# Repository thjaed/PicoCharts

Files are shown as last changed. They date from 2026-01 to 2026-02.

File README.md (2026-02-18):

# PicoCharts
 PicoCharts is a pocket-sized embedded device that lets students view their timetable, homework, behaviour, and attendance without needing a phone. I built this device using a Raspberry Pi Pico 2 W and I am using an online API for the data (ClassCharts). Hence the name "PicoCharts".

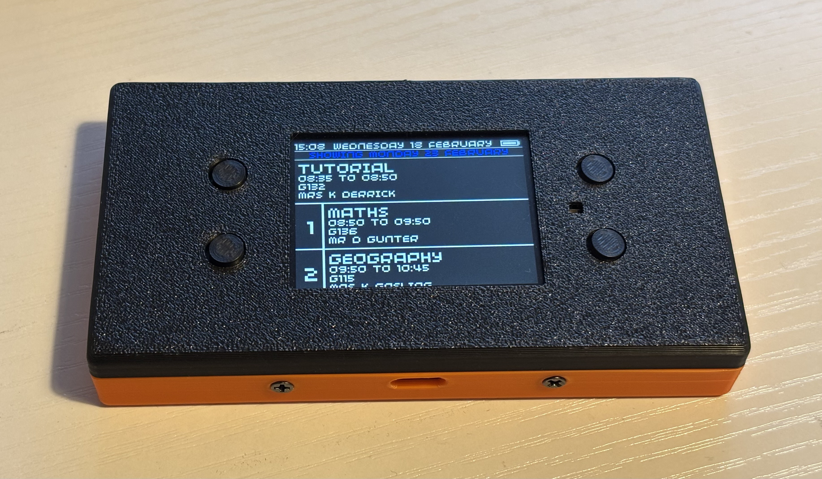
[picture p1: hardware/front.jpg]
Front
 

## Backstory
 After my school banned the use of mobile phones, I had the idea of creating a device that could let me view my timetable at school. This was also a good opportunity to improve my hardware design & soldering skills, and to improve my programming.
 
 The project started by just reading an exported calendar file from Outlook (project [cal-pal](https://github.com/thjaed/cal-pal)), but quickly grew after I upgraded to the Pico 2 W with wireless connectivity. I found documentation for the API of the platform my school uses, thank you to the creators of https://classchartsapi.github.io/api-docs/, without this community resource my project would not have been possible. I developed a Python & MicroPython wrapper for the API (https://github.com/thjaed/classcharts-api-python) which is accessible for anyone else wanting to integrate with the ClassCharts API.

## Features
 Here are some features of PicoCharts:

 ### Timetable
  - Label next to lessons with homework due
  - Timetables for different days can be viewed
  - Custom breaks can be added, e.g. Lunch or Break
  - 'Next' label on lessons
  - Lessons in the past are automatically removed
  - Auto-updates after a new day
  - View timetables for different days and store them offline

 ### Homework
  - Front LED turns on if there is unseen homework
  - Description can be viewed by clicking on a homework task
  - Due-date colour coded to make it clear if a homework is late or not
  - Homework marked as seen on ClassCharts when it is clicked on

 ### Attendance
  - Colour-coded background based on percentage
  - Easily choose a time range (Since August, This Week or Last Week)

 ### Behaviour
  - Easily choose a time range (Since August, This Week or Last Week)

## Using PicoCharts yourself
 To use PicoCharts, all you need is a Raspberry Pi Pico 2 W and a Pimoroni Pico Display Pack 2.0" (No soldering required, just attach a headered Pico 2 W to the back of the Pico Display). The Pico LiPo SHIM is only required if you want to use PicoCharts with a battery and the Adafruit LC709203F is only required if you want the battery percentage in the corner of the screen. Note that you will need to solder these battery boards.

 In terms of software, you need to install [Pimoroni's MicroPython build](https://github.com/pimoroni/pimoroni-pico-rp2350/releases/latest) to your Pico. Then copy everything in the [src](/src/) folder to your Pico. You can do this in the IDE 'Thonny'.
 
 Make sure to modify [secrets.py](/src/secrets.py), this is where you put your ClassCharts login details and WiFi networks.
 
 In [config.py](/src/config.py), you can change settings such as timezone and brightness. This is also where you define what times your breaks are, so make sure to change the times to reflect your school day. Disable ENABLE_BATTERY_gauge (enabled by default) if you are not using the battery gauge.

 If you decide to replicate my hardware, there are [STL Files](/hardware/stl_files/) for my design.

## Hardware
 ### I used the following hardware:
  - Pimoroni Pico Display Pack 2.0" - this is the screen and has the built in buttons and RGB LED
  - Raspberry Pi Pico 2W
  - Adafruit LC709203F battery fuel gauge - measure the charge level of the battery
  - Pimoroni Pico LiPo SHIM
  - USB-C breakout board with 512K resistors (so it works with modern chargers)
  - 1200mAh LiPo battery

At the start, I was using the Pico Display with the Pico plugged in to the headers on the back. But this made the device too thick so I decided to remove the headers from the display and solder 30 AWG wire directly. In the process of removing the headers I accidentally ripped off some pads (I had bad equipment) including the 3V supply. But luckily I traced it back to a resistor and soldered on to it, which saved the screen.

I used a USB-C breakout board to add USB-C. I soldered to the touch pads underneath the Pi to get USB data signals working over it, so I can program the Pi through the USB-C port as well.

 ### Wiring diagram
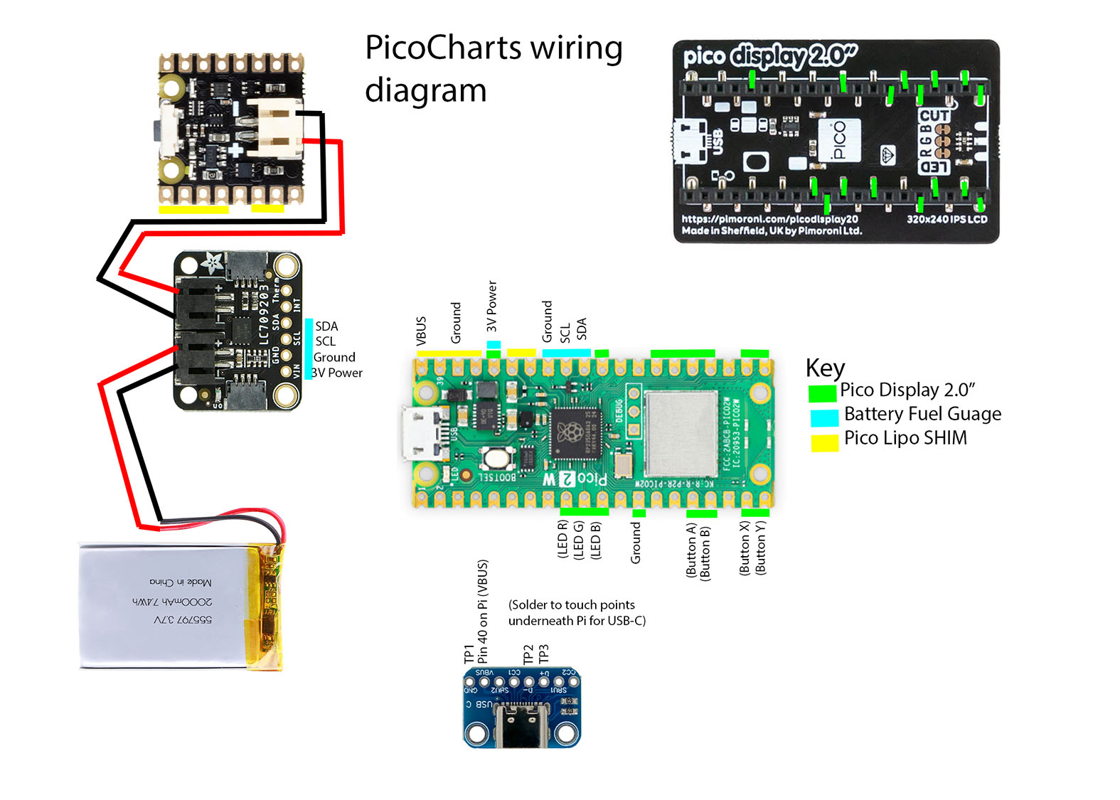
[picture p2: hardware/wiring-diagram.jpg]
Wiring Diagram
  

 ### Internals
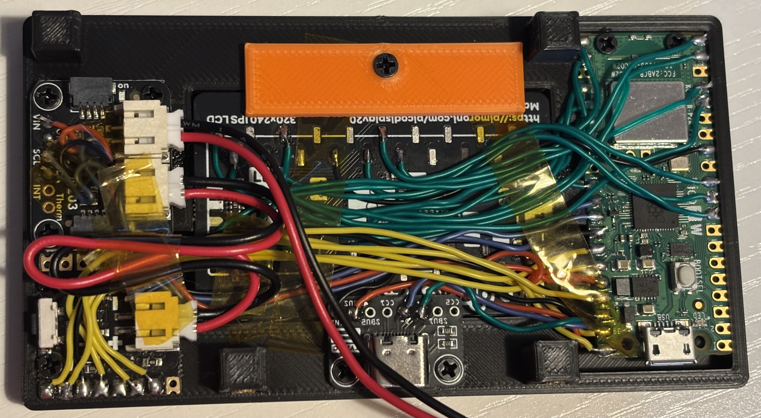
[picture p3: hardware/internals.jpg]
Internals
  
  
 ### Back
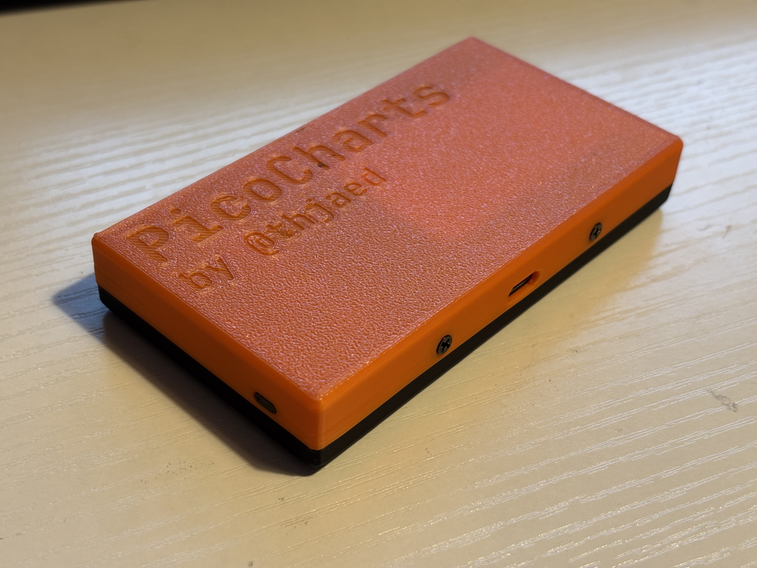
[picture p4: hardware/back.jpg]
Back
  

## Software
 ### High-level overview
  PicoCharts gets and displays data by first requesting data from the ClassCharts API. This happens at bootup and at a set interval, when the device is sleeping. This data is then simplified and saved into a JSON file in the flash storage. When a page is opened on the device, the corresponding file is read and loaded into a list. This list is then read by a draw function, which then puts the data on the screen inside scrollable pages and organised boxes.

  If the user requests to view the timetable for a different day and the JSON file for that day is not saved, then the data is requested and saved into a new JSON file. If the file already exists, it is opened with little to no waiting.
 
 ### Use of AI generated code
  AI was used selectively for complex date arithmetic and initial scrolling logic. All AI-assisted code is clearly commented.

## Acknowledgements
 In this project I used:

 - pybuttons by @oscaracena - https://github.com/oscaracena/pybuttons
 - ClassCharts API Docs  by @veloii - https://github.com/classchartsapi/api-docs
 - PicoGraphics by @pimoroni - https://github.com/pimoroni/pimoroni-pico/tree/main/micropython/modules/picographics
 - MicroPython_LC709203F by @chris-reichl - https://github.com/chris-reichl/MicroPython_LC709203F
 - I based my 3D printed case on: Pimoroni Pico Display pack 2.0 Case by @PMcGregor_848641 - https://www.printables.com/model/473270-pimoroni-pico-display-pack-20-case

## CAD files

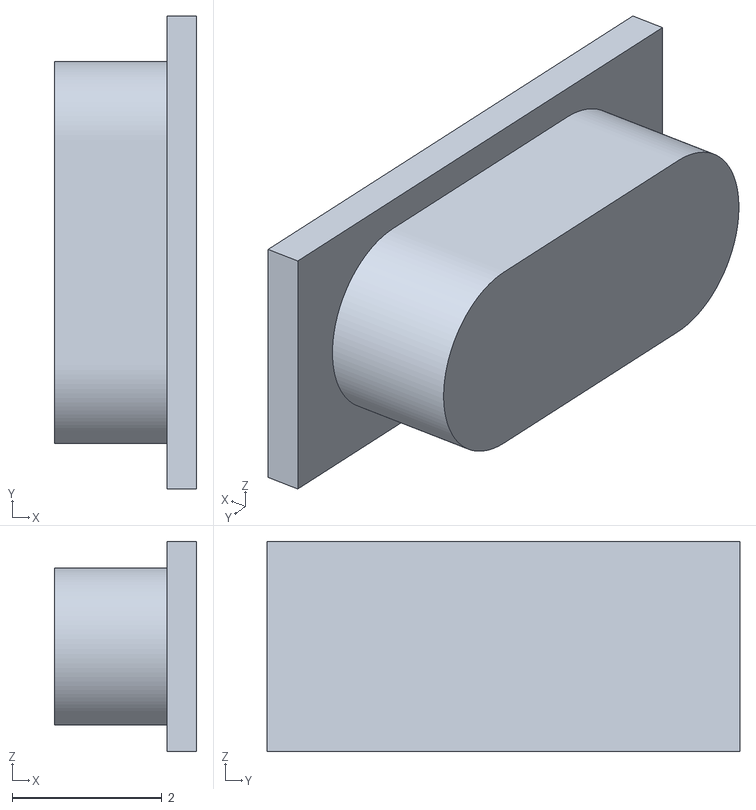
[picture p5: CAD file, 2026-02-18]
hardware/stl_files/pwr_btn.stl
1.90 x 6.30 x 2.80

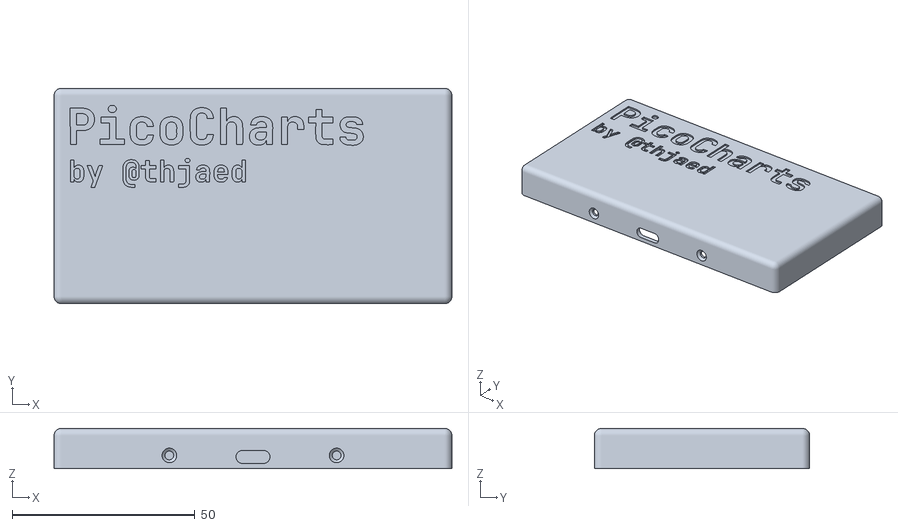
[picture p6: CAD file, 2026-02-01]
hardware/stl_files/back_cover.stl
109.0 x 59.0 x 11.0

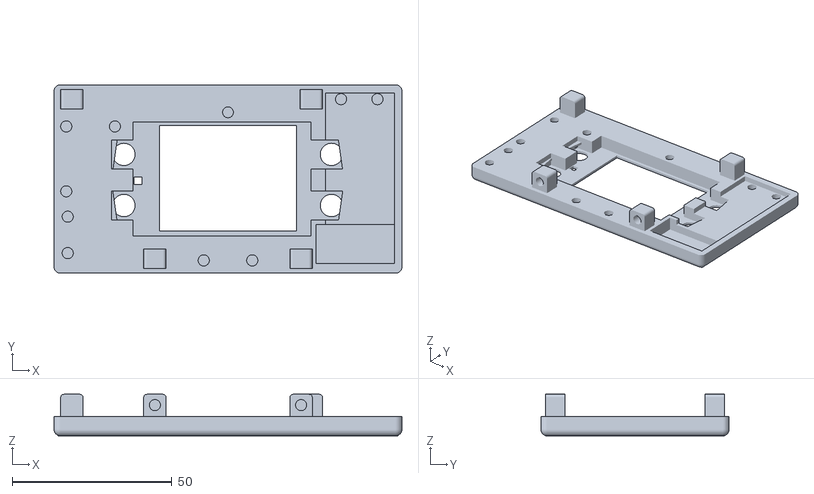
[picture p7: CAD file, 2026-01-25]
hardware/stl_files/base.stl
109.0 x 59.0 x 13.0

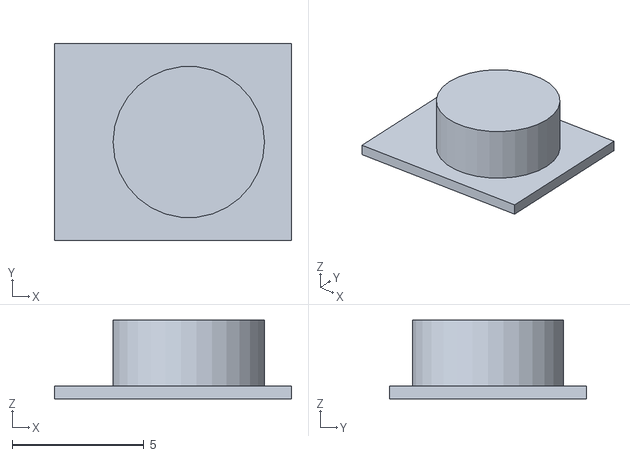
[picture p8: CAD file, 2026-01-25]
hardware/stl_files/X_Y_buttons.stl
9.00 x 7.50 x 3.00

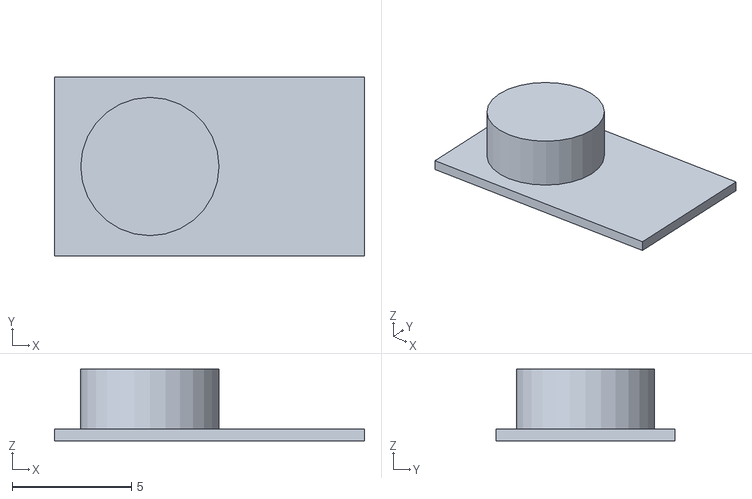
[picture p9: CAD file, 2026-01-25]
hardware/stl_files/A_B_buttons.stl
13.0 x 7.50 x 3.00

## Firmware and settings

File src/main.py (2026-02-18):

import asyncio
import utime # type: ignore
import sys

from pybuttons import Button
from classcharts import ClassCharts
import ui
import clock
import wifi
import config
import state
if config.ENABLE_BATTERY_GAUGE: import battery

classcharts = ClassCharts()
message = ui.message
bar = ui.bar
led = ui.led
hwviewer = ui.hwviewer
timetable = ui.timetable
timetable_change_date = ui.TimetableChangeDate()
menu = ui.Menu()
behaviour = ui.Behaviour()
attendance = ui.Attendence()
homework = ui.Homework()
bootscreen = ui.BootScreen()

fps = 30
display_update_time = int((1/fps) * 1000) # Calculates time to sleep in ms
ui.setup()

def press_handler(btn, pattern):
    state.UI.last_interaction_time = utime.time()
    if state.UI.sleeping:
        device_wake_up()
    else:
        if pattern == Button.SINGLE_PRESS:
            if btn.get_id() == BUTTON_A:
                if ui.page == "menu":
                    menu_exec() # Run the code associated with the button
                elif ui.page == "behaviour":
                    behaviour.toggle_time_range()
                    behaviour.draw()
                elif ui.page == "attendance":
                    attendance.toggle_time_range()
                    attendance.draw()
                elif ui.page == "homework":
                    homework.select()
                elif ui.page == "timetable":
                    timetable_change_date.go()
                elif ui.page == "timetable_change_date":
                    timetable_change_date.select()

            if btn.get_id() == BUTTON_B:
                if ui.page == "homework_viewer":
                    homework.go()
                elif ui.page == "menu": # Go to timetable page
                    timetable.go()
                elif ui.page == "timetable_change_date":
                    timetable.go()
                elif ui.page != "menu": # Go to menu page
                    menu.go()

            if btn.get_id() == BUTTON_X:
                if ui.page == "timetable": # Scroll events page up
                    timetable.scroll(direction="up")
                elif ui.page == "homework":
                    homework.scroll(direction="up")
                elif ui.page == "homework_viewer":
                    hwviewer.scroll(direction="up")
                elif ui.page == "menu": # Highlight the button above
                    menu.scroll(direction="up")
                elif ui.page == "timetable_change_date":
                    timetable_change_date.scroll(direction="back")

            elif btn.get_id() == BUTTON_Y:
                if ui.page == "timetable":  # Scroll events page down
                    timetable.scroll(direction="down")
                elif ui.page == "homework":
                    homework.scroll(direction="down")
                elif ui.page == "homework_viewer":
                    hwviewer.scroll(direction="down")
                elif ui.page == "menu": # Highlight the button below
                    menu.scroll(direction="down")
                elif ui.page == "timetable_change_date":
                    timetable_change_date.scroll(direction="forward")

def menu_exec():
        # Executes code for selected entry
        name = menu.entries[menu.selected]

        if name == "Timetable":
            timetable.go()
        
        elif name == "Behaviour":
            behaviour.go()
        
        elif name == "Attendance":
            attendance.go()
        
        elif name == "Homework":
            homework.go()        
        
        elif name == "Connect and Refresh Data":
            led.update("updating_data", True)
            for text in wifi.wifi_connect():
                message.show(text)
    
            if state.WiFi.connected:
                for text in clock.set_time_ntp():
                    message.show(text)
                get_data(print_type="message", background=False)
            else:
                message.show("OFFLINE")
                utime.sleep(1)

            led.update("updating_data", False)
            timetable.go()
        
def device_to_sleep():
    # Turns off screen
    state.UI.sleeping = True
    ui.screen_off()

def device_wake_up():
    # Turns on screen
    if state.UI.reset_page_after_sleep:
        timetable.go()
    state.UI.reset_page_after_sleep = False
    state.UI.sleeping = False
    ui.screen_on()

def get_data(print_type, background):
    if (wifi.test_connection() and ((state.UI.sleeping and background) or (not background))
        and state.Clock.rtc_set):
        led.update("updating_data", True)

        for text in classcharts.save_data():
            if print_type == "console": print(text)
            elif print_type == "message": message.show(text)
            elif print_type == "boot": bootscreen.print(text)

        led.update("updating_data", False)

        # Turn LED on if there are unseen hw tasks
        led.update("unseen_homework", len(state.Homework.unseen_ids) > 0)

async def monitor_buttons():
    # Watches for input on buttons
    while True:
        for btn in buttons:
            btn.read()
        await asyncio.sleep_ms(10) # 10ms poll time

async def update_menu_bar():
    while True:
        if (ui.page != "menu" and
            ui.page != "timetable_change_date" and
            not state.UI.sleeping
            ):
            bar.draw()
        await asyncio.sleep_ms(1000) # Refresh menu bar every sec

async def sleep_handler():
    # Puts screen to sleep after certain time has elapsed from last interaction
    while True:
        time = utime.time()
        if state.UI.sleeping and time - config.SLEEP_TIME_SEC - 600 > state.UI.last_interaction_time:
            state.UI.reset_page_after_sleep = True
        if not state.UI.sleeping and time - config.SLEEP_TIME_SEC > state.UI.last_interaction_time:
            device_to_sleep()
        await asyncio.sleep(1)

async def update_data():
    await asyncio.sleep(config.DATA_UPDATE_INTERVAL)
    # Periodically updates data
    while True:
        get_data(print_type="console", background=True)
        await asyncio.sleep(config.DATA_UPDATE_INTERVAL)

async def connection_tester():
    # Periodically check for wifi connectivity
    while True:
        if not wifi.test_connection() and state.UI.sleeping:
            # attempt to connect if there is no connection
            led.update("wifi_connecting", True)
            wifi.wifi_connect()
            led.update("wifi_connecting", False)

        await asyncio.sleep(30)
    
def init():
    # Startup sequence
    led.update("booting", True)
    bootscreen.draw()
    if config.ENABLE_BATTERY_GAUGE:
        bootscreen.print("Initialising Battery")
        battery.init()
    for text in wifi.wifi_connect():
        bootscreen.print(text)
    if state.WiFi.connected:
        for text in clock.set_time_ntp():
            bootscreen.print(text)
        get_data(print_type="boot", background=False)
    
    # Starts functions that need to be run asyncrously
    asyncio.create_task(monitor_buttons())
    asyncio.create_task(update_menu_bar())
    if not config.FORCE_OFFLINE:
        asyncio.create_task(connection_tester())
        asyncio.create_task(update_data())

    # Start monitoring time to sleep
    state.UI.last_interaction_time = utime.time()
    asyncio.create_task(sleep_handler())
    
    # Draw UI
    timetable.go()

    print("Finished startup")
    led.update("booting", False)

async def main():
    init()
    while True:
        # Refresh screen if awake
        if not state.UI.sleeping:
            ui.update()
        await asyncio.sleep_ms(display_update_time)

# Button setup
PINS = [12, 13, 14, 15]
BUTTON_A = 12
BUTTON_B = 13
BUTTON_X = 14
BUTTON_Y = 15

buttons = []
for pin in PINS:
    btn = Button(Button.MODE_DIGITAL, pin)
    btn.on_press(press_handler) \
       .on_press_for(press_handler, 700)  # 700ms = long press
    buttons.append(btn)

# Start main loop
try:
    asyncio.run(main())
except KeyboardInterrupt:
    print("Goodbye!")
    ui.cleanup()
    sys.exit()

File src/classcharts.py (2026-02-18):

import ujson # type: ignore
import utime # type: ignore
import os

from uclasscharts_api import StudentClient
import clock
import secrets
import config
import state

def strip_tags(text):
    # removes HTML tags from a string
    out = ""
    in_tag = False
    for c in text:
        if c == "<":
            # start of tag
            in_tag = True
        elif c == ">":
            # end of tag
            in_tag = False
        elif not in_tag:
            # add character to output if not inside tag
            out += c
    return out

def convert_text(text):
    # replace chars
    text = text.replace("\r\n", "\n").replace("\r", "\n")
    text = text.replace("</p>", "§§")
    text = text.replace("<br>", " ")
    text = text.replace("\n", " ")
    text = text.replace("§§", "\n\n")
    text = text.replace("&nbsp;", " ")
    text = text.replace("\"", "'")

    # remove useless spaces
    while "  " in text:
        text = text.replace("  ", " ")

    # remove spaces after newlines
    text = text.replace("\n ", "\n")

    # remove useless blank lines
    while "\n\n\n" in text:
        text = text.replace("\n\n\n", "\n\n")
    
    # remove any leftover HTML tags
    text = strip_tags(text)

    # remove spaces at start and end
    text = text.strip()

    return text

class ClassCharts:
    def login(self):
        # Authenticate with ClassCharts API
        self.client = StudentClient(code=secrets.CC_CODE, dob=secrets.CC_DOB)

    def save_data(self):
        yield "Logging In"
        self.login()
        yield "Getting Homework"
        self.save_homework(login=False)
        if state.Clock.rtc_set and f"timetable_{clock.secs_to_date()}.jsonl" not in os.listdir():
            # only save if there is no file
            yield "Getting Timetable"
            self.save_timetable(login=False)
        yield "Getting Behaviour"
        self.save_behaviour(login=False)
        yield "Getting Attendance"
        self.save_attendance(login=False)

        yield "All data saved"

    def save_timetable(self, date=None, login=True):
        if login: self.login()
        # Query API
        if date is None:
            date = clock.secs_to_date()
        response = self.client.get_lessons(date=date)
        lessons = response["data"]
        meta = response["meta"]
        
        timetable = []
        
        for lesson in lessons:
            period_code = lesson["period_number"] # Period code is either REG, 1, 2, RB2, 3, 4, 5
            # Uses metadata response to match period code to start and end times
            for period in meta["periods"]:
                if period["number"] == period_code: 
                    start_time = period["start_time"][:5] # Gets start time in HH:MM format
                    end_time = period["end_time"][:5] # Gets end time in HH:MM format
                    
            subject = lesson["subject_name"]
            teacher = lesson["teacher_name"]
            room = lesson["room_name"]

            if not period_code.isdigit():
                # Don't add a period code if it is not a number, e.g. REG or RB2
                period_code = None
            
            # Word Replacements
            if subject == "Art & Design - Photography": subject = "Photography"
                
            # Put data in json format so it can be saved to a file
            timetable.append({
                "subject": subject,
                "teacher": teacher,
                "room": room,
                "time": f"{start_time} to {end_time}",
                "start": clock.clock_str_to_secs(clock_str=start_time, date=date),
                "end": clock.clock_str_to_secs(clock_str=end_time, date=date),
                "period_num": period_code,
                "type": "lesson",
                "date": date
            })

        if len(timetable) > 0:
            for b in config.BREAKS:
                start = b["start"]
                end = b["end"]
            
                timetable.append(
                    {
                        "name": b["name"],
                        "time": f"{start} to {end}",
                        "start": clock.clock_str_to_secs(start, date=date),
                        "end": clock.clock_str_to_secs(end, date=date),
                        "type": "break"
                    }
                )

        # Sorts timetable by start time
        timetable = sorted(timetable, key=lambda x: x["start"]) # I am so proud of this one-liner lol

        # Write data to file
        file_name = f"timetable_{date}.jsonl"
        with open(file_name, "w") as f:
            for event in timetable:
                ujson.dump(event, f)
                f.write("\n")
        
    def save_behaviour(self, login=True):
        if login: self.login()

        behaviour = []
        times = ["august", "this_week", "last_week"]

        # Query API
        for time in times:
            if time == "august":
                response = self.client.get_behaviour(from_date=clock.august(), to_date=clock.secs_to_date())
            elif time == "this_week":
                response = self.client.get_behaviour(from_date=clock.this_monday(), to_date=clock.secs_to_date())
            elif time == "last_week":
                last_week = clock.last_week()
                response = self.client.get_behaviour(from_date=last_week[0], to_date=last_week[1])

            data = response["data"]

            total_positive = 0
            total_negative = 0

            # Loop through points for each reason and sum them together to get total
            for i in data["negative_reasons"]:
                total_negative += data["negative_reasons"][i]

            for i in data["positive_reasons"]:
                total_positive += data["positive_reasons"][i]

            # Store in json format
            behaviour.append({
                "time": time,
                "positive": str(total_positive),
                "negative": f"-{total_negative}" if total_negative > 0 else str(total_negative)
            })

        # Save data to file
        with open("behaviour.jsonl", "w") as f:
            for line in behaviour:
                ujson.dump(line, f)
                f.write("\n")


    def save_attendance(self, login=True):
        if login: self.login()

        attendance = []
        times = ["this_week", "last_week"]

        # Query API
        for time in times:
            if time == "this_week":
                response = self.client.get_attendance(from_date=clock.this_monday(), to_date=clock.secs_to_date())
                since_august = response["meta"]["percentage_singe_august"]
            elif time == "last_week":
                last_week = clock.last_week()
                response = self.client.get_attendance(from_date=last_week[0], to_date=last_week[1])

            meta = response["meta"]
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

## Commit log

2026-01-22 no longer display completed hw
    [ui.py]
2026-01-25 added some stl files & battery support
    [A_B_buttons.stl, X_Y_buttons.stl, base.stl]
2026-01-31 Implement battery management with retry logic and state handling
2026-01-31 Fix API bug in title replacement and increase data update interval to 20 minutes
    [classcharts.py, main.py]
2026-02-01 fixed bugs in offline mode
    [main.py, ui.py]
2026-02-01 added back cover and power button stl
    [back_cover.stl, pwr_btn.stl]
2026-02-03 Refactor LED status management and improve data update handling
2026-02-04 reverted going to timetable after sleep
    [main.py]
2026-02-04 bugfix: 'next' label no longer shown on timetables other than today
    [ui.py]
2026-02-11 bugfix: timetable for current day no longer deleted when it is the oldest file
    [config.py, ui.py]
2026-02-12 bugfix: error in calculating timestamp for future lessons
    [classcharts.py, clock.py, ui.py]
2026-02-18 improved imports, added button, and added wiring diagram
    [pwr_btn.stl]
